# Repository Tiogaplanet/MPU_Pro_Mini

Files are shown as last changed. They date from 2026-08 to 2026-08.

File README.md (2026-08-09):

# MiP Power Up - Pro Mini
An Arduino Pro Mini adapter board for the WowWee MiP robot.  The three files in the `MPU Pro Mini` folder are written in Eagle, are based on Sparkfun's original MiP ProMini Pack, and were updated by [adamgreen](https://github.com/adamgreen) to use the 5-volt, 16 MHz version of the ATmega328p.

While these files can be used to print the MiP Power Up - Pro Mini printed circuit board (PCB), some knowledge in doing so is expected on the part of the user.

An update is pending that will migrate the project to KiCAD, and provide support and tutorials to the user.

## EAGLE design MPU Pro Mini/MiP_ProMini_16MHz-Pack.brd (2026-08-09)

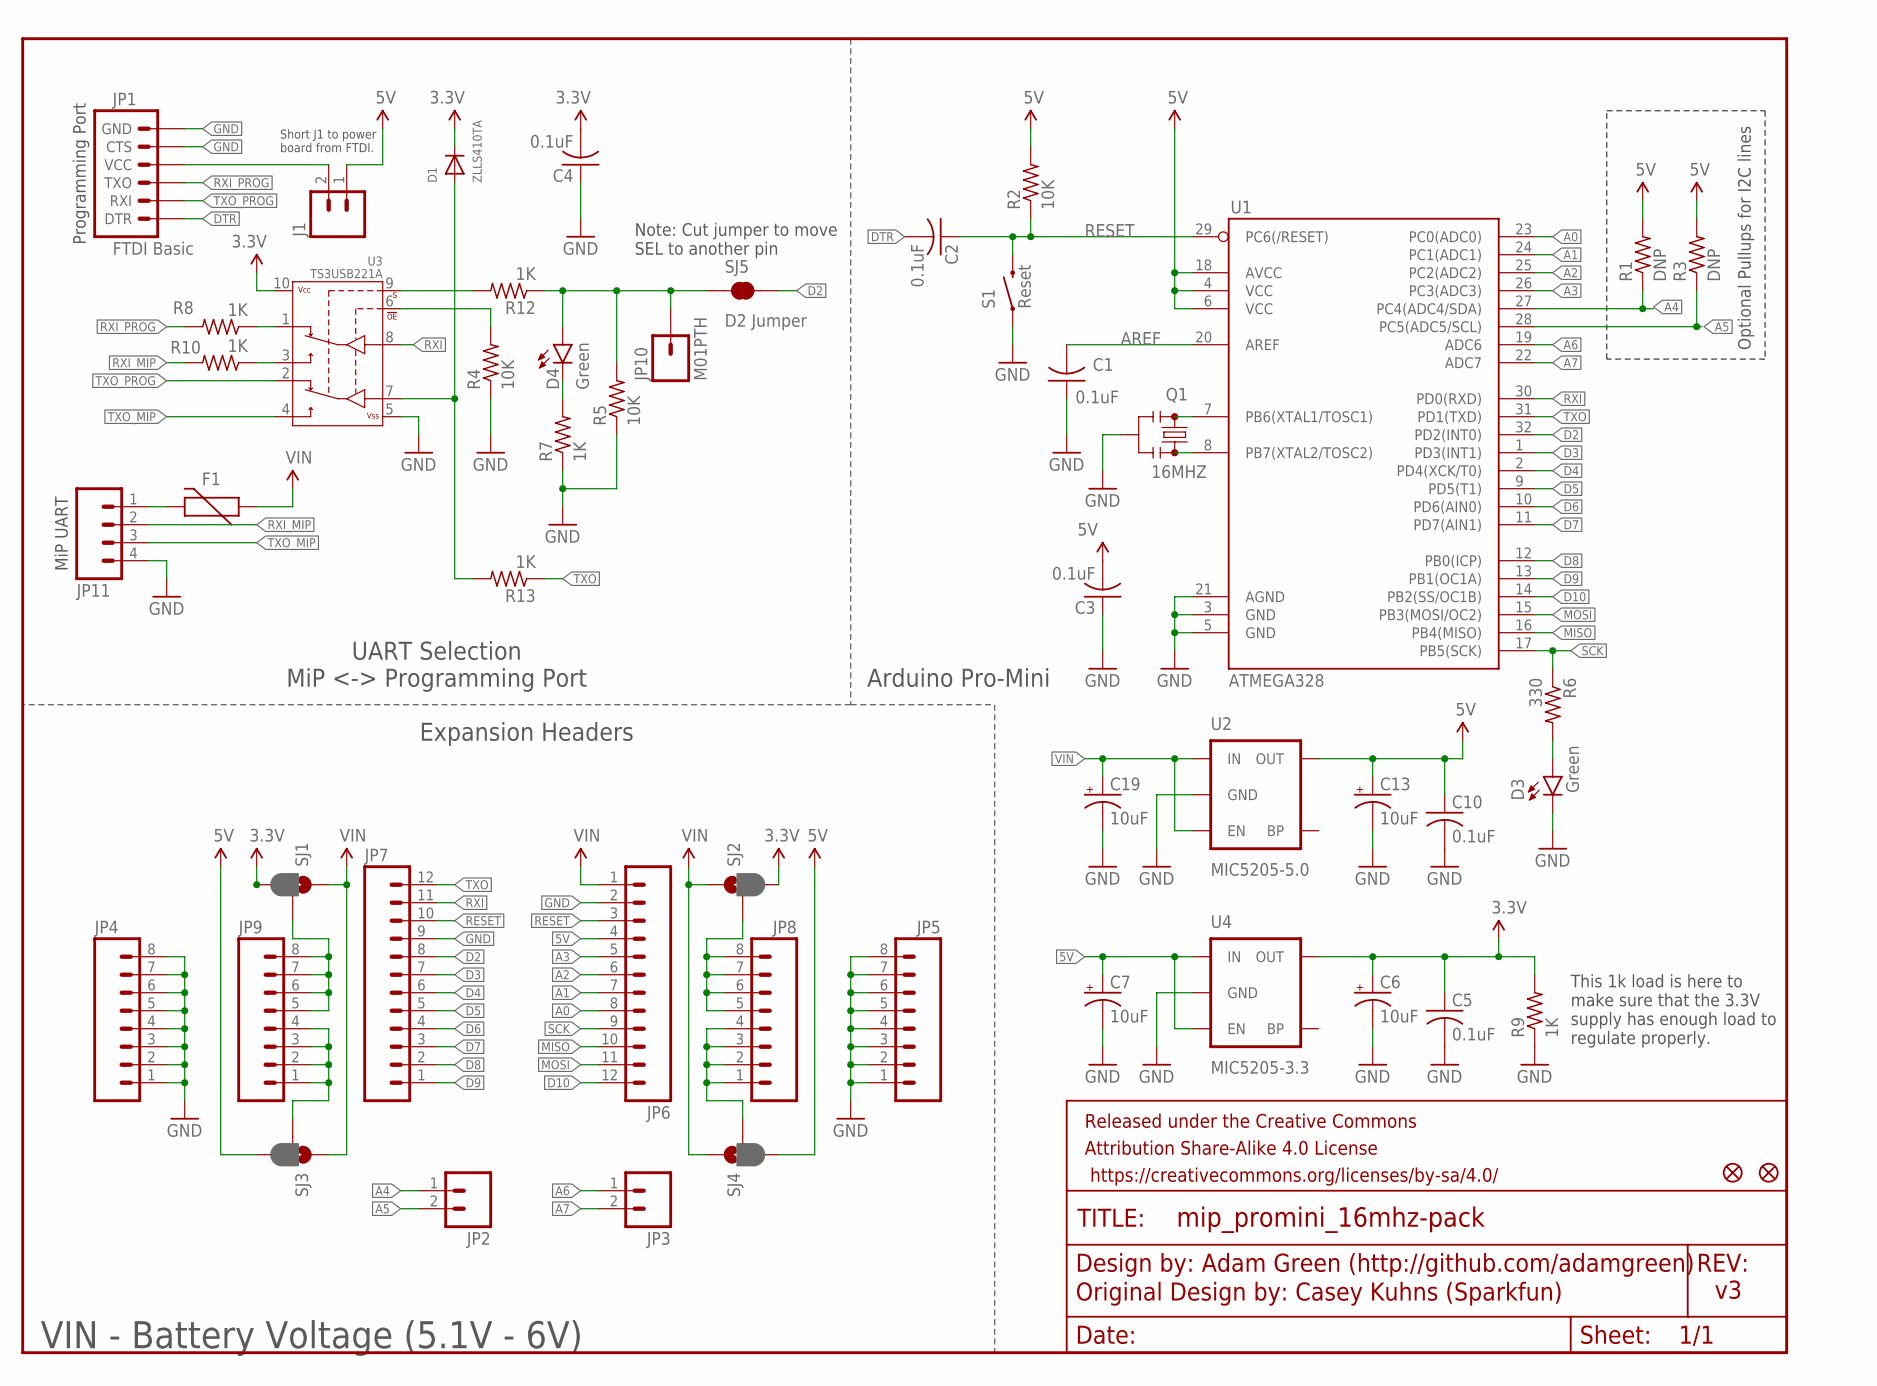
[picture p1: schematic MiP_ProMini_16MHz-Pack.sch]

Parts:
C1, C2, C3, C4, C5, C10: 0.1uF; C0805
C6, C7, C13, C19: 10uF; EIA3216
D1: ZLLS410TA; SOD-323F
D3, D4: Green; LED-0603
F1: PTCCUSTOM; PTC-1206-CUSTOM
FID1, FID2: FIDUCIAL1X2; FIDUCIAL-1X2
FRAME1: FRAME-LETTER; CREATIVE_COMMONS
J1: M02PTH; 1X02
JP1: FTDI Basic; 1X06
JP2, JP3: M02PTH; 1X02
JP4, JP5, JP8, JP9: M081X08; 1X08
JP6, JP7: M12PTH; 1X12
JP10: M01PTH; 1X01
JP11: M04JST; 1X04-1.5MM_JST
Q1: 16MHZ; RESONATOR-SMD-CUSTOM
R1, R3: DNP; R0805
R2, R4, R5: 10K; R0805
R6: 330; R0805
R7, R8, R9, R10, R12, R13: 1K; R0805
S1: Reset; TACTILE-SWITCH-SMD-CKN9112CT-ND
SJ1, SJ2, SJ3, SJ4: JUMPER-PAD-3-2OF3_NC_BY_PASTE; PAD-JUMPER-3-2OF3_NC_BY_PASTE_YES_SILK_FULL_BOX
SJ5: D2 Jumper; PAD-JUMPER-2-NC_BY_TRACE_YES_SILK
U1: ATMEGA328; TQFP32-08
U2: MIC5205-5.0; SOT23-5
U3: TS3USB221A; QFN-10-RSE-CUSTOM
U4: MIC5205-3.3; SOT23-5

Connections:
3.3V: C4.2, C5.1, C6.A (+), D1.C, R9.2, SJ1.3, SJ2.3, U3.10 (VCC), U4.5 (OUT)
5V: C3.2, C7.A (+), C10.1, C13.A (+), J1.1, JP6.4, R1.2, R2.2, R3.2, SJ3.3, SJ4.3, U1.4 (VCC), U1.6 (VCC), U1.18 (AVCC), U2.5 (OUT), U4.1 (IN), U4.3 (EN)
A0: JP6.8, U1.23 (PC0(ADC0))
A1: JP6.7, U1.24 (PC1(ADC1))
A2: JP6.6, U1.25 (PC2(ADC2))
A3: JP6.5, U1.26 (PC3(ADC3))
A4: JP2.1, R1.1, U1.27 (PC4(ADC4/SDA))
A5: JP2.2, R3.1, U1.28 (PC5(ADC5/SCL))
A6: JP3.1, U1.19 (ADC6)
A7: JP3.2, U1.22 (ADC7)
AREF: C1.2, U1.20 (AREF)
D2: JP7.8, SJ5.2, U1.32 (PD2(INT0))
D3: JP7.7, U1.1 (PD3(INT1))
D4: JP7.6, U1.2 (PD4(XCK/T0))
D5: JP7.5, U1.9 (PD5(T1))
D6: JP7.4, U1.10 (PD6(AIN0))
D7: JP7.3, U1.11 (PD7(AIN1))
D8: JP7.2, U1.12 (PB0(ICP))
D9: JP7.1, U1.13 (PB1(OC1A))
D10: JP6.12, U1.14 (PB2(SS/OC1B))
DTR: C2.2, JP1.1 (DTR)
GND: C1.1, C3.1, C4.1, C5.2, C6.C (-), C7.C (-), C10.2, C13.C (-), C19.C (-), D3.C, JP1.5 (CTS), JP1.6 (GND), JP4.1, JP4.2, JP4.3, JP4.4, JP4.5, JP4.6, JP4.7, JP4.8, JP5.1, JP5.2, JP5.3, JP5.4, JP5.5, JP5.6, JP5.7, JP5.8, JP6.2, JP7.9, JP11.4, Q1.2, R4.1, R5.1, R7.1, R9.1, S1.1, U1.3 (GND), U1.5 (GND), U1.21 (AGND), U2.2 (GND), U3.5 (VSS), U4.2 (GND)
MISO: JP6.10, U1.16 (PB4(MISO))
MOSI: JP6.11, U1.15 (PB3(MOSI/OC2))
unnamed: Q1.3, U1.8 (PB7(XTAL2/TOSC2))
unnamed: JP9.5, JP9.6, JP9.7, JP9.8, SJ1.2
unnamed: JP9.1, JP9.2, JP9.3, JP9.4, SJ3.2
unnamed: Q1.1, U1.7 (PB6(XTAL1/TOSC1))
unnamed: JP8.5, JP8.6, JP8.7, JP8.8, SJ2.2
unnamed: JP8.1, JP8.2, JP8.3, JP8.4, SJ4.2
unnamed: D3.A, R6.2
unnamed: D4.C, R7.2
unnamed: R10.1, U3.3 (2D+)
unnamed: R8.1, U3.1 (1D+)
unnamed: R4.2, U3.6 (!OE)
unnamed: J1.2, JP1.4 (VCC)
unnamed: R12.2, U3.9 (S)
unnamed: F1.2, JP11.1
unnamed: D1.A, R13.2, U3.7 (D-)
RESET: C2.1, JP6.3, JP7.10, R2.1, S1.3 (2), U1.29 (PC6(/RESET))
RXI: JP7.11, U1.30 (PD0(RXD)), U3.8 (D+)
RXI_MIP: JP11.2, R10.2
RXI_PROG: JP1.3 (TXO), R8.2
SCK: JP6.9, R6.1, U1.17 (PB5(SCK))
SELECT: D4.A, JP10.1, R5.2, R12.1, SJ5.1
TXO: JP7.12, R13.1, U1.31 (PD1(TXD))
TXO_MIP: JP11.3, U3.4 (2D-)
TXO_PROG: JP1.2 (RXI), U3.2 (1D-)
VIN: C19.A (+), F1.1, JP6.1, SJ1.1, SJ2.1, SJ3.1, SJ4.1, U2.1 (IN), U2.3 (EN)

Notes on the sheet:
Optional Pullups for I2C lines
Adam Green (http://github.com/adamgreen)
Note: Cut jumper to move SEL to another pin
MiP UART
Programming Port
UART Selection MiP <-> Programming Port
Expansion Headers
Arduino Pro-Mini
VIN - Battery Voltage (5.1V - 6V)
Original Design by: Casey Kuhns (Sparkfun)
Short J1 to power board from FTDI.
This 1k load is here to make sure that the 3.3V supply has enough load to regulate properly.

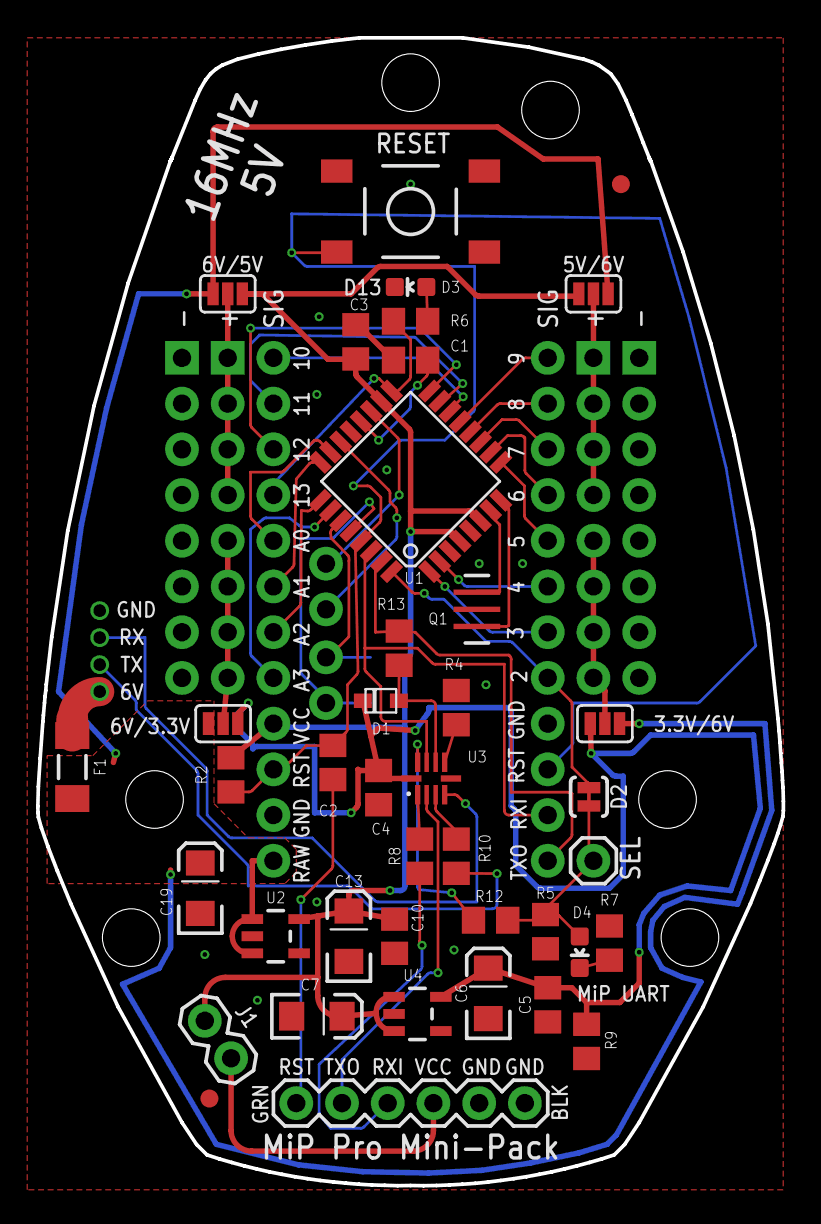
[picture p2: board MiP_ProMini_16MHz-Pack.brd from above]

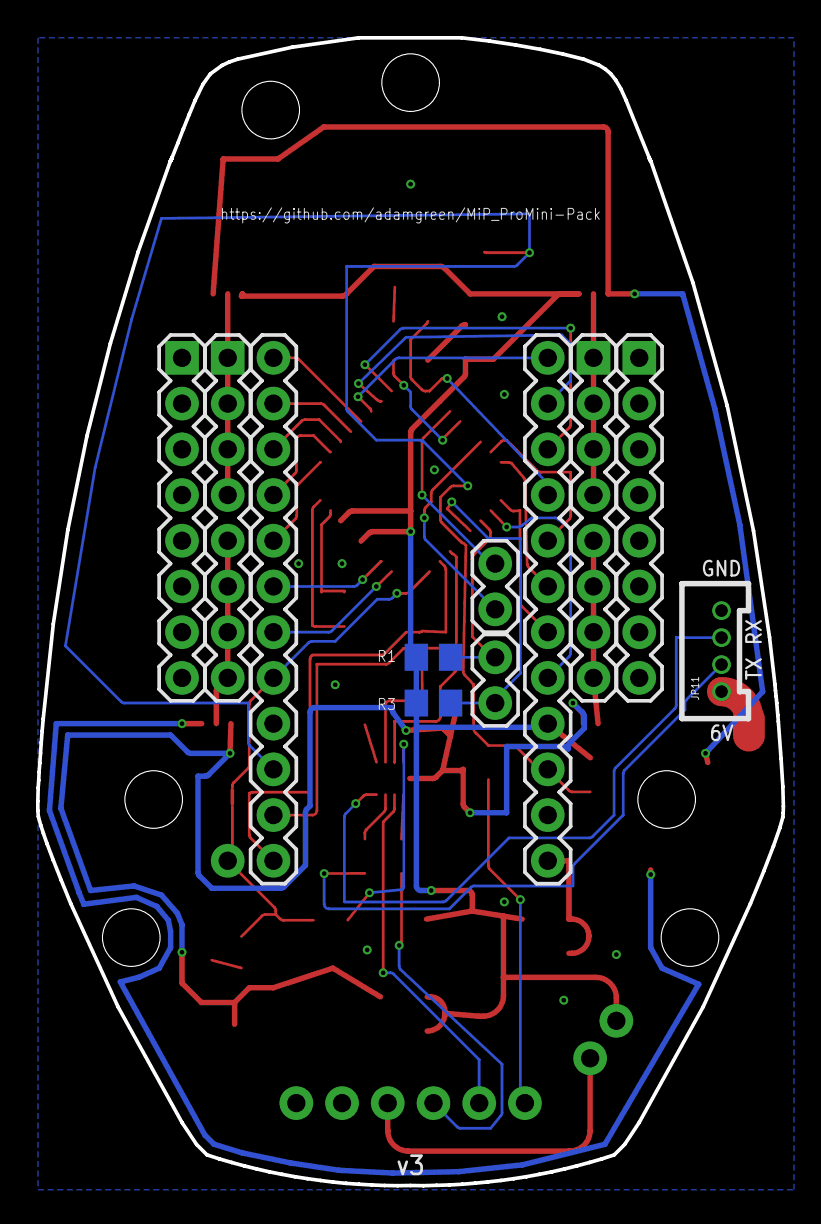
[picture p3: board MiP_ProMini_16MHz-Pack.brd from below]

Board: 2 copper layers, 41.4 x 63.8 mm, 52 parts (11 on the bottom side), 49 nets.

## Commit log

2026-08-09 Original project
    [MiP_ProMini_16MHz-Pack.brd, MiP_ProMini_16MHz-Pack.sch]
2026-08-09 Rename project to 'MiP Power Up - Pro Mini'
    Updated project title and clarified description.

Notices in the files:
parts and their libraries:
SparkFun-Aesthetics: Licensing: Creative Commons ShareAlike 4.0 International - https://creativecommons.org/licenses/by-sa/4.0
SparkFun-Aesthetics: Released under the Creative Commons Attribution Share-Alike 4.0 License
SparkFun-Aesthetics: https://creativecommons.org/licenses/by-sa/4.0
